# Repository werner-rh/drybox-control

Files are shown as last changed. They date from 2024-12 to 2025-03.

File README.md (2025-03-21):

DryBox dryController
===

## Version 0.50 ESP 01

## Requirements
- Arduino IDE 1.8.2 or higher
- NewliquidCrystal (I2C) https://github.com/fmalpartida/New-LiquidCrystal/tree/master
- ESP8266: PubSubClient by Nick O'Leary
- SEP8266: ArduinoJson by Benoit Blanchon

- 3D printing files and other parts list: https://www.printables.com/de/model/724722-filament-dry-box-heated-ventilated-arduino-control
- Improved version: https://www.printables.com/model/1093573-enhanced-filament-dry-box-heated-ventilated-arduin

## Description
Controller for an active heated and ventilated Filament DryBox. The Dryer contains a PTC Heater and a Fan for fresh dry air.

Original version is for Arduino Nano
Improved Version is for Wemos D1 Mini (ESP8266); additional features:
- sensor data transmission via mqtt
- example files for mqtt --> telegraf --> influxdb --> grafana
- PCB layout in kicad
- ==> pay attention to set your wifi credentials in Secrets.h (for ESP8266)

With one Heater, the box may barely reaches 55 degree. As max i reached 57 degree. I recommend not to go over 52-53 degree. If you need higher temperatures, install a second heater. The MosFet switch will manage this. But you also need a stronger power supply (12V, 8-10A). A simple improvement is insulating the walls inside. I used a car sun protect shield, with reflection and insulating. This improves the performance of the box sigifignant. The warm up is much faster and also eaysier to to reach 55 degrees.

## Recommended drying temperatures
- PLA, PLA+                : 40-45 degree
- ABS, ABS+,  PETG         : 45-50 degree
- PVA,PVB, ASA, TPU, PMMA  : 50-55 degree

## Trouble shooting for ESP8266 version
- Check step by step in the chain  esp --> mqtt --> telegraf --> influxdb --> grafana
- Let DryBox run for all of the following tests.
- esp: Check the serial console: Is wifi working? Do you have a mqtt connection? Have you changed the corresponding parameters in Secrets.h?
- mqtt: Use the commandline or the tool mqtt explorer to observe the mqtt messages from DryBox. There should be a main node labeled like in Secrets.h
- telegraf: telegraf has input and output interfaces. First check the log for any errors in the input interface. Then check if the output interface wrote into the file listed in telegraf.conf. If this is working, you can comment out the file section in telegraf.conf. Now check telegraf´s output interface to influxdb. Do you have set the influxdb token in telegraf.conf?
- influxdb: Have you generated a bucket "DryBox" an configured this in Secrets.h? Have you generated a token connected to the bucket for telegraf and grafana with the necessary permissions? Use the influxdb data explorer to check if any DryBox data is written from telegraf.
- grafana: Have you created a datasource "InfluxDB" with query language "flux"? Is the organization (e.g. "Homelab") the same in the config files for telegraf, influxdb and grafana? Did you use the right token from influxdb? Did you select the configured datasource when importing the grafana.json file?

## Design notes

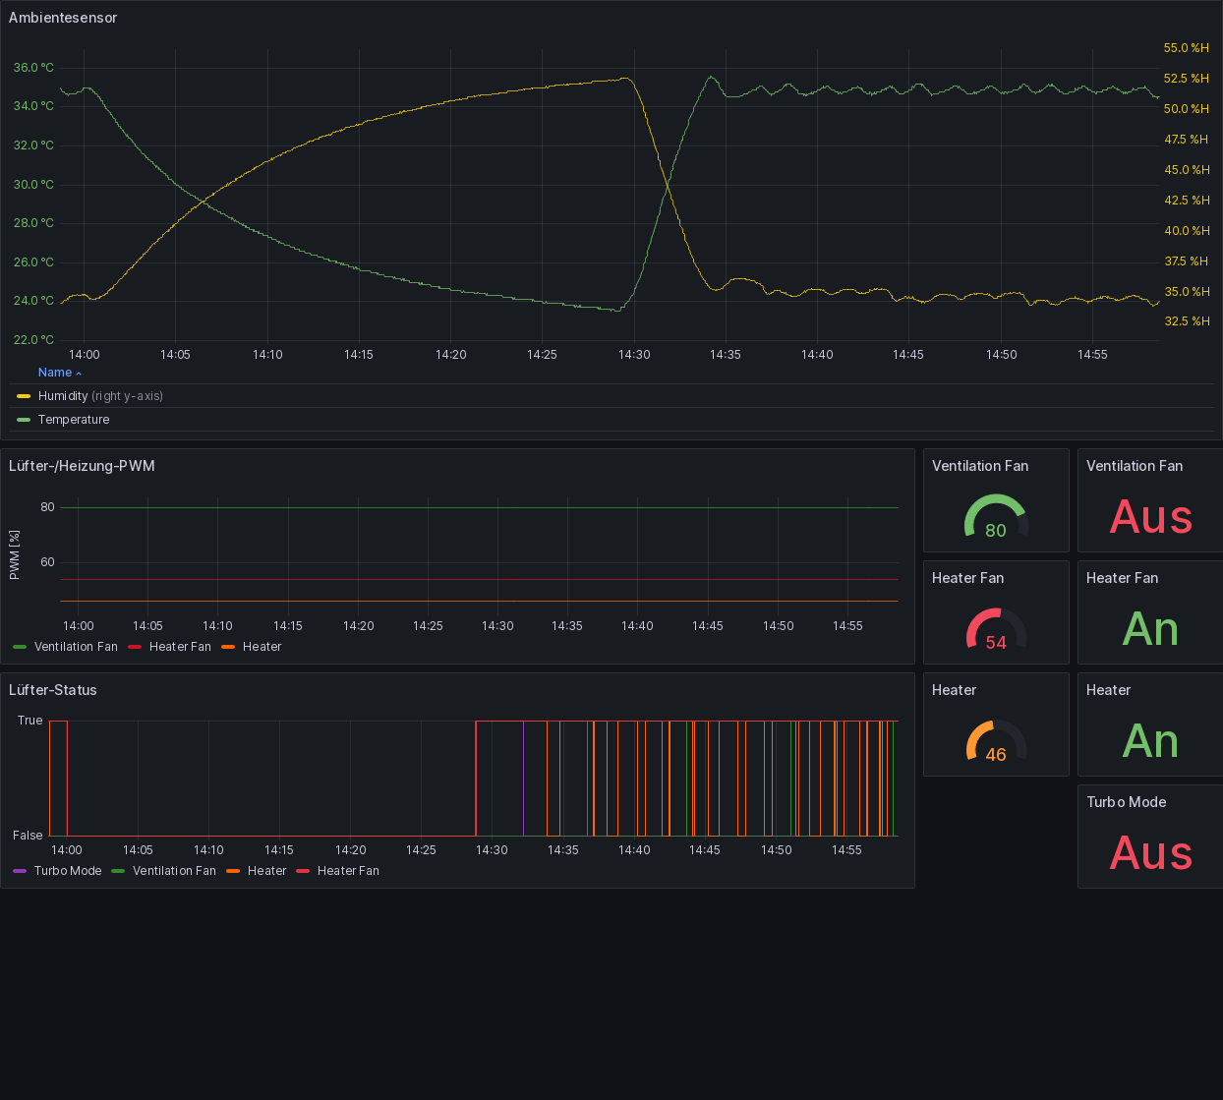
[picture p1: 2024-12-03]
helpers/DryBox-Dashboards-Grafana.png

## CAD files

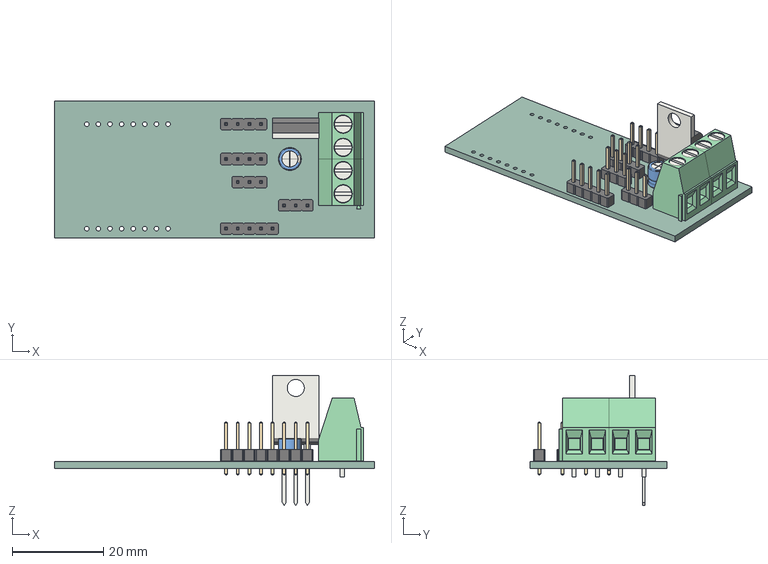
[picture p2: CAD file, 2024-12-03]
DryBoxControlPlatine/DryBoxControlPlatine.step
70.0 x 30.0 x 28.5 mm
DryBoxControlPlatine PCB

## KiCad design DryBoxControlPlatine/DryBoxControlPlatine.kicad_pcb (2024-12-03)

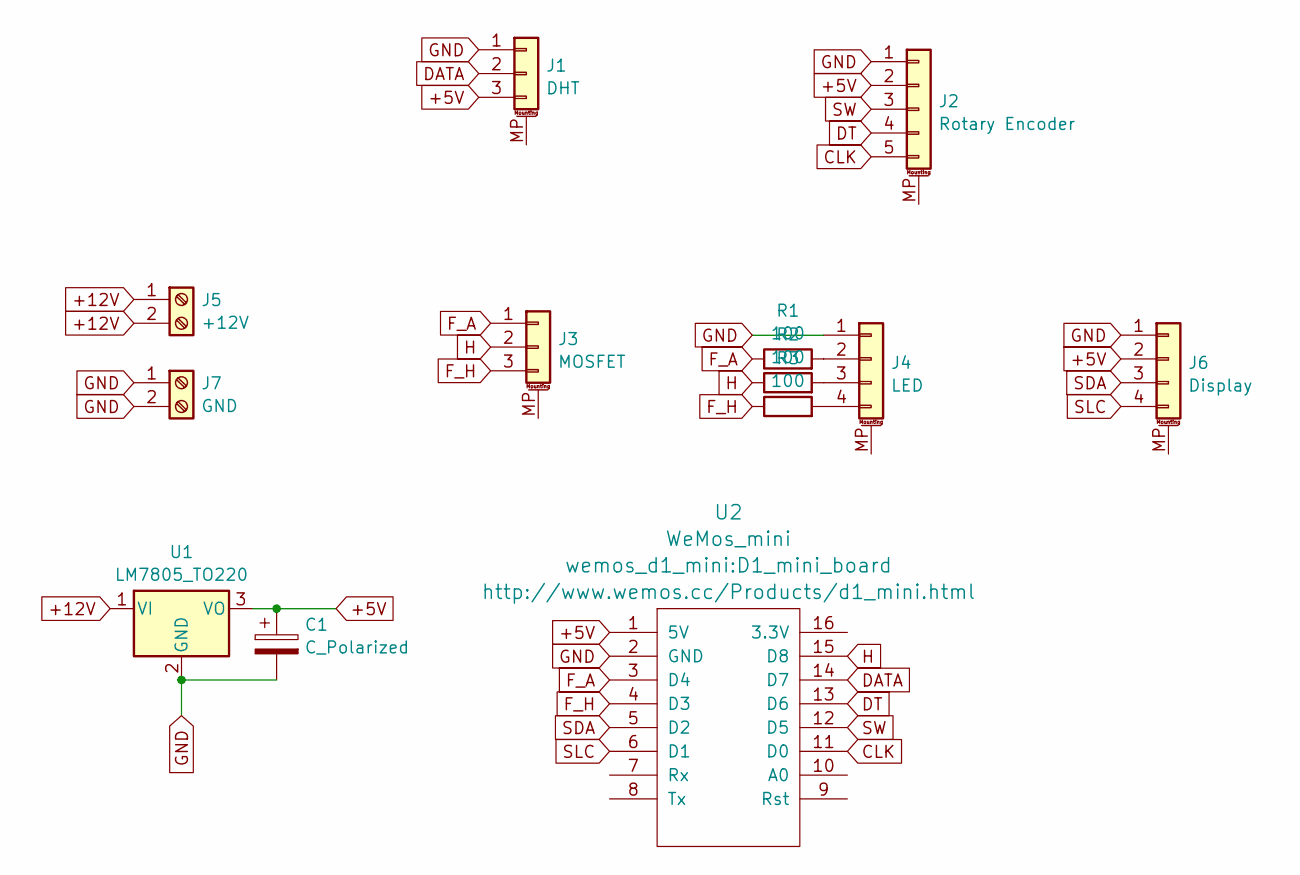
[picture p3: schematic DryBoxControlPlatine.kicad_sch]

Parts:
C1: C_Polarized; CP_Radial_D5.0mm_P2.50mm
J1: DHT; PinHeader_1x03_P2.54mm_Vertical
J2: Rotary Encoder; PinHeader_1x05_P2.54mm_Vertical
J3: MOSFET; PinHeader_1x03_P2.54mm_Vertical
J4: LED; PinHeader_1x04_P2.54mm_Vertical
J5: +12V; TerminalBlock_Phoenix_MKDS-1,5-2-5.08_1x02_P5.08mm_Horizont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
J6: Display; PinHeader_1x04_P2.54mm_Vertical
J7: GND; TerminalBlock_Phoenix_MKDS-1,5-2-5.08_1x02_P5.08mm_Horizont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
R1, R2, R3: 100; R_Axial_DIN0204_L3.6mm_D1.6mm_P2.54mm_Vertical
U1: LM7805_TO220; TO-220-3_Vertical
U2: WeMos_mini; D1_mini_board

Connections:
+5V: C1.1, J1.3, J2.2, J6.2, U1.3 (VO), U2.1 (5V)
+12V: J5.1, J5.2, U1.1 (VI)
CLK: J2.5, U2.11 (D0)
DATA: J1.2, U2.14 (D7)
DT: J2.4, U2.13 (D6)
F_A: J3.1, R1.1, U2.3 (D4)
F_H: J3.3, R3.1, U2.4 (D3)
GND: C1.2, J1.1, J2.1, J4.1, J6.1, J7.1, J7.2, U1.2 (GND), U2.2 (GND)
H: J3.2, R2.1, U2.15 (D8)
unnamed: J4.2, R1.2
unnamed: J4.3, R2.2
unnamed: J4.4, R3.2
SDA: J6.3, U2.5 (D2)
SLC: J6.4, U2.6 (D1)
SW: J2.3, U2.12 (D5)

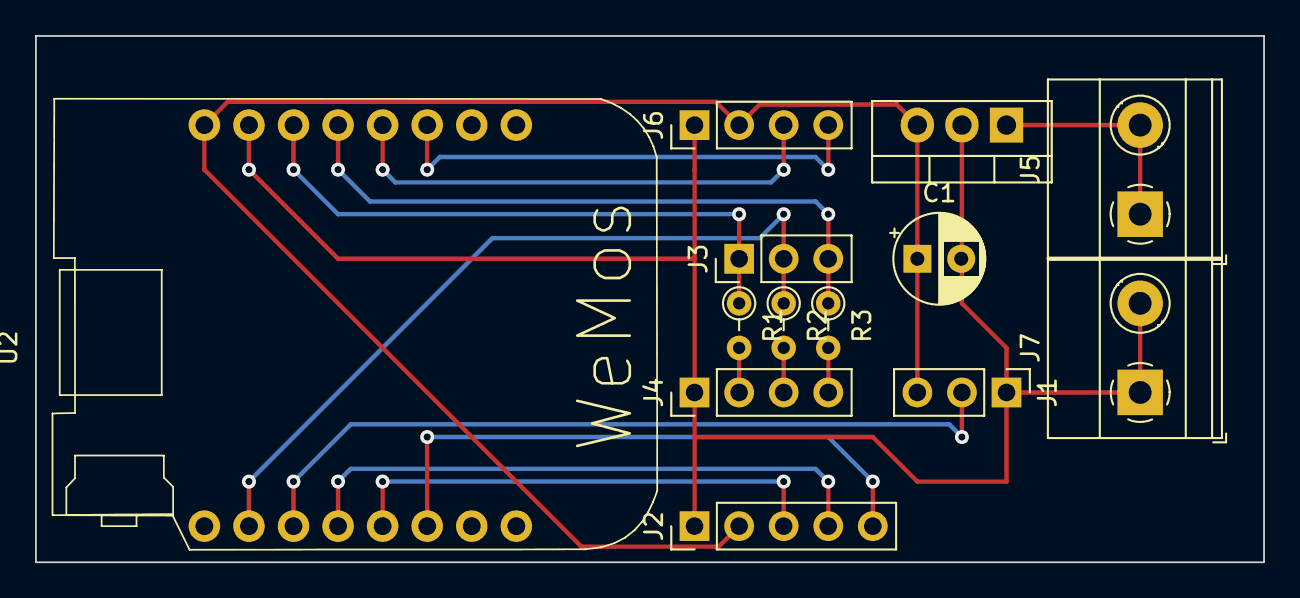
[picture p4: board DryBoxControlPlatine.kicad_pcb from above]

Board: 2 copper layers, 70.0 x 30.0 mm, 13 parts (0 on the bottom side), 15 nets.

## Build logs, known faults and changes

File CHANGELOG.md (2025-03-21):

# Changelog
All notable changes for this project will be documented in this file

## [0.50 ESP 01] - 2025-03-21
### Added
- Trouble shooting guide for ESP in README
### changed
- grafana.json for better import management without UIDs
- Versioning for ESP branch now with separate version tag
 
## [0.50] - 2024-12-02
### Added
- Port to platform ESP8266 (Wemos D1 Mini): software timer interrupt handling; wifi; Secrets.h for wifi and mqtt config
- MQTT for ESP8266: Publish sensor data
- ESP8266: Example configs for telegraf and grafana for transport and visualisation of sensor data
- ESP8266: PCB layout
### changed
- Handling sensor error: Added a retry mechanism for reading sensor data if sensor is temporarily offline.

## [0.49] - 2024-06-18
### Added
- Handling sensor error. If sensor fails during drying cycle, then drying process will be stopped and error message appear on the screen.
  
## [0.48] - 2024-05-08
### changed
- Refactoring Heating data. All values for heating power and heater fan speed are handled in an own class 
### Added
- Turbo mode for faster heating up in the lower ranges
- values for ventialtion time and final ventilation time
- replaced fix define for air exchange intervall with value in HeatingData

## [0.47] - 2024-05-05
### changed
- bugfix in function dryController(). Heater now is shut down after ventilation.
- bugfix in rampUpTable. Range over 50 degrees wasn't regarded and so powered to low.
### Added
- additional range over over 45 and 50 degrees. Now there are 6 ranges.
- display showing state of heater, heaterfan and ventilation during drying.
- refactored initializing power values for each tempeture range.
- adjust current values for low Hysteresis

## [0.46]
### Added
- last final ventilation after dry process is finished

## [0.45]
### Added
- first final version

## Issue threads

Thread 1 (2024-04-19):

avoid temp overshoot

derFliegendeHamburger, 2024-04-19:
as general safety measure or if heater runs during ventilation phase, the temp could rise way above the desired target drying temperature.
cure: add a test and emergency stop for the heater  right after reading the sensor.

werner-rh, 2024-04-19:
The heater only runs until the destination temperature is reached. The it is switched off. The heater also don't run during ventilation. After switch off the heater doesn't cool down immediately. So the temperature may increase a lttle bit over the destination. This is a normal Hysteresis in temperature controll processes.

Anyway, the heater is a PTC element. It can't overheat.

werner-rh, 2024-04-19:
There is no need for an emergency stop within the normal Hysteresis. The temperature is reading as fast as the DHT11 is able to deliver and the values are immediately handled.

Closed 2024-04-19.

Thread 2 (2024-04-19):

timing is wrong by factor 2

derFliegendeHamburger, 2024-04-19:
in my setup I have to half the timing counters from 100 down to 50 and from 6000 down to 3000 respectively to get proper timing

werner-rh, 2024-05-06:
there might be something wrong on your side. The timing is controlled by interrupt in chain of the milli second timer. My timing fits like a swiss clock. Are you using something different? Usb serial or some other thing?

derFliegendeHamburger, 2024-05-11:
different hardware, yes. For arduino software relevant differences are
i2c sensor SHT41, 4-pin pwm fans require 4kHz pwm signal, 20x4 display, usb debug output.

werner-rh, 2024-05-12:
The usb debug output might crash your timing. Have you tried it without usb serial output?

derFliegendeHamburger, 2024-05-17:
yes, no difference.
I can see my other problem related to timing - the display gets garbled. From past projects I know this happens when the display (driver and or firmware and or hardware) suffers from too frequent requests.
Not sure if the 20x04 display is particularly slow but I like the extra space for output.
It will take some more time to diagnose this further and possibly adopt code accordingly.

werner-rh, 2024-05-18:
I never tried a 20x4 until now. The two lines more might be the problem, because they are forcing a lot more traffic on the I2C. Even with the 16x2 display, only particluar ranges are updated, because this also needs a lot of time. Maybe you can use a parallel interface for the display. That would be much faster. The DryBox it self doesn't need much I/Os.

derFliegendeHamburger, 2024-05-26:
- reduced i2c bus speed to 100kHz,
- replaced 4wire ribbon cable for  i2c wiring to i2c sensor sht41 with shorter CAT5 shielded cable
working, solved

werner-rh, 2024-06-01:
Sounds good! Great!

Closed 2024-05-26.

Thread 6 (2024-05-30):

Question wrt to ventilation cycle

derFliegendeHamburger, 2024-05-30:
in the process of drying, the ventilation is activated every 4 minutes with 20 seconds runtime.
Are these specifics accidental or do you have any 'theory' or testing scheme behind this?

Reason for me asking is that my drybox is built to hold 4Kg spools, so it is quite larger and holds more air and more mass than the typical dryer.

werner-rh, 2024-06-01:
The interval of 4 minutes and 20 seconds are evaluated with the 10L Box. In combination i had a good ventilation for this box and not to much temperature drop. For a 4kg spool, your box must be quite bigger. So you have to find out, which are the best parameter. Take a look at version 0.48. I have refactored the code a bit and you now have all adjustable parameter at one place in file HeatinData.cpp. This might be easier to try out the parameters you need.

werner-rh, 2024-07-04:
can be closed

Closed 2024-07-04.

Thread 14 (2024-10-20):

Misspelling of PWM

jofland, 2024-10-20:
Misspelling in HeatingData.h

```
uint8_t ventilationFanPWN;
//PWN
```

should be

```
uint8_t ventilationFanPWM;
//PWM
```

werner-rh, 2024-12-03:
Fixed in v0.49.1

Closed 2024-12-03.

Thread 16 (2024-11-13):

Encoder Button not configured

bmchughs, 2024-11-13:
I had issue with the Arduino sketch, specifically the encoder 'button' was not working.  Looking at the sketch I included the code below on line 157 and it resolved the issue.

` pinMode(EncSwitch, INPUT_PULLUP);`

I don't see that the 'EncSwitch' was configured to be an 'input' anywhere in the sketch.  Once I included this bit of code, it worked perfectly fine.

werner-rh, 2024-12-01:
Yes you are right. I found it now. But i don't know why, my Encoder works fine even without the input config ;) - i will fix it.

werner-rh, 2024-12-03:
Fixed in v0.49.1

Closed 2024-12-03.

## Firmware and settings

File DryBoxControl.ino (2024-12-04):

/***
   Project: DryBox Control
   File   : DryBoxControl.ino
   Author : Werner Riemann
   Created: 18.10.2023
   Board: Arduino Nano

   Description: Controller for an active (heated) Filament DryBox.
                The Dryer contains a PTC Heater and a Fan for fresh dry air.

   Recommended drying temperatures:
      PLA, PLA+                : 40-45 degree
      ABS, ABS+,  PETG         : 45-50 degree
      PVA,PVB, ASA, TPU, PMMA  : 50-55 degree

     Note: with one Heater, the box may barely reaches 55 degree. As max i reached 57 degree.
           I recommend not to go over 52-53 degree. If you need higher temperatures,
           install a second heater. The MosFet switch will manage this. But you
           also need a stronger power supply (12V, 8-10A).

   Pins:

   Arduino
   A4,A5  - I2C Display control (A4 - SDA, A5 - SCL)
   Wemos D1 Mini
   5=D1, 4=D2  - I2C Display control (D2 - SDA, D1 - SCL)



   D2     - not used
   D1     - not used
   D3     - not used
   D4     - not used

   Arduino
   D5     - Rotary Encoder Switch
   D6     - Rotary Encoder DT_pin                 Note: some encoder are different and you may have to change DT and CLK Pin.
   D7     - Rotary Encoder CLK_pin                      Clockwise spin should increase all values.
   D8     - Digital in DHT11 sensor
   D9     - Analog out PWM Fan Air exchange
   D10    - Analog out PWM Fan Heating
   D11    - Analog out PWM Heating
   D12    -

   Wemos D1 Mini
   14=D5     - Rotary Encoder Switch
   12=D6     - Rotary Encoder DT_pin                 Note: some encoder are different and you may have to change DT and CLK Pin.
   16=D0     - Rotary Encoder CLK_pin                      Clockwise spin should increase all values.
   13=D7     - Digital in DHT11 sensor
   0=D3     - Analog out PWM Fan Air exchange
   2=D4     - Analog out PWM Fan Heating
   15=D8    - Analog out PWM Heating

   D13    - Digital out LEDPIN 13 (interne LED)


   --- Menu and functions ---
   Main select: Temperature, Time, Start, Save, Version, Test functions (press Rotary to choose)
   Temperature: change value by rotate, press to Rotary to exit
   Time       : choose hour, minutes or Ret to exit. Press Rotary to enter value to change. Press Rotary again to exit value change.
   Start      : press Rotary to start drying. Press Rotary during drying to pause or exit drying
   Save       : press Rotary to save current setting for temperature and time to eeprom
   Version    : shows the current version, press Rotary again to return to main
   Test       : provides 3 functions for Heater, Heater Fan, Air Fan for Fresh air supply and exit Test.
                On exit Test menu, all values are set to zero and stops all modules.

                This is useful to check all modules separately after assembling modules. Keep in mind to don't power
                up the heater without the fan for a longer time.
*/

#include <SPI.h>
#include <Wire.h>
#include <EEPROM.h>
#include <Arduino.h>
#include <DHT.h>
#include "DryBoxControl.h"
#include "WRKeyStateDef.h"
#include "DryBoxDisplay.h"
#include "HeatingData.h"

#ifdef ESP8266
  #include <Ticker.h>
  #include <ESP8266WiFi.h>
  #include <PubSubClient.h>
  #include <ArduinoJson.h>
  #include "Secrets.h"
#endif

// defines for DHT11 Temp and Humitidy Sensor
#ifdef ARDUINO_AVR_NANO
  #define DHTPIN 8        // Digital pin connected to the DHT sensor
  int EncSwitch = 5;
  int DT_pin = 6;   //swap lines to change direction on the encoder
  int CLK_pin = 7;  //swap lines to change direction on the encoder
#elif ESP8266
  #define DHTPIN 13        // Digital pin connected to the DHT sensor
  int EncSwitch = 14;
  int DT_pin = 16;   //swap lines to change direction on the encoder
  int CLK_pin = 12;   //swap lines to change direction on the encoder
  Ticker timer;
  bool mqttConnected = false;
#else
  #error "Unsupported platform"
#endif

//#define DHTTYPE DHT11   // chose the DHT type you are using
#define DHTTYPE DHT22

volatile uint8_t B100HzToggle = 0;  // 100 Hertz Signal
uint8_t ui10MilliSekCount = 0;

int encoder_value = 500;
int last_encoder_value  = 500;
int DT_pinstate;
int last_DT_pinstate;

int AirFanSpeed = 100;    // Extract Fan Speed in Percent
int HeatFanSpeed = 50;    // HeatFan Speed in Percent
int HeatingPower = 25;    // Heating Power in Percent

int testAirFanSpeed = 0;    // Extract Fan Speed in Percent for testing mode
int testHeatFanSpeed = 0;   // HeatFan Speed in Percent for testing mode
int testHeatingPower = 0;   // Heating Power in Percent for testing mode

// default values at startup, if nothing is stored in the eeprom
int DryTemperature = 35;    // Destination Dry Temperature in degree celsius
int DryTime_Hours = 1;
int DryTime_Minutes = 30;
int curDryTime_Hours = 1;
int curDryTime_Minutes = 30;

//-- adjustable seetings for drying process, stored in HeatingData class
HeatingData heatingData;    // see HeatingData class


//-- State var for rotary encoder weitch  ----
uint8_t encoderBUTTON_State = 0;

//-- Remember State on for Heater, Heater Fan and Ventilation
boolean StateHeaterOn = false;
boolean StateHeaterFanOn = false;
boolean StateVentilationOn = false;
boolean turboMode = false;

DryBoxDisplay display;
DHT dht(DHTPIN, DHTTYPE);

#ifdef ESP8266
  WiFiClient espClient;
  PubSubClient mqtt_client(espClient);
  
  void connectToWiFi() {
    WiFi.begin(ssid, password);
    Serial.print("Connecting to WiFi");
    unsigned long startAttemptTime = millis();
    const unsigned long timeout = 10000;
  
    while (WiFi.status() != WL_CONNECTED && millis() - startAttemptTime < timeout) {
      delay(500);
      Serial.print(".");
    }
    if (WiFi.status() == WL_CONNECTED) {
      Serial.println("\nConnected to the WiFi network");
    } else {
      Serial.println("\nFailed to connect to WiFi. Continuing without WiFi.");
    }
  }
  
  
  void connectToMQTTBroker() {
    unsigned long startAttemptTime = millis();
    const unsigned long timeout = 5000;
    if (!WiFi.isConnected()) {
      return;
    }

    while (!mqtt_client.connected() && millis() - startAttemptTime < timeout) {
      String client_id = String(mqtt_topic) + String("-")  + String(WiFi.macAddress());
      Serial.printf("Connecting to MQTT Broker as %s.....\n", client_id.c_str());
      if (mqtt_client.connect(client_id.c_str(), mqtt_username, mqtt_password, (String(mqtt_topic) + "/status").c_str(), 0, true, "offline")) {
        Serial.println("Connected to MQTT broker");
        mqttConnected = true;
        mqtt_client.setBufferSize(1024);
        mqtt_client.subscribe(mqtt_topic);
        mqtt_client.publish((String(mqtt_topic) + "/status").c_str(), "online", true);
        return;
      } else {
        Serial.print("Failed to connect to MQTT broker, rc=");
        Serial.print(mqtt_client.state());
        Serial.println(" try again...");
      }
      delay(1000);
    }
    mqttConnected = false;
  }
#endif



/***
   Saves the current settings for temperature, drying hours and minutes
*/
void SaveSettings() {
  EEPROM.write(0, (uint8_t) 17);
  EEPROM.write(1, (uint8_t) DryTemperature);
  EEPROM.write(2, (uint8_t) DryTime_Hours);
  EEPROM.write(3, (uint8_t) DryTime_Minutes);
}


/***
   Reads the last saved settings for temperature, drying hours and minutes
*/
void ReadSettings() {
  uint8_t isInit = EEPROM.read(0);

  if (isInit == 17) {
    DryTemperature = EEPROM.read(1);
    DryTime_Hours = EEPROM.read(2);
    DryTime_Minutes = EEPROM.read(3);
  }
}


// Interrupt is called once a millisecond,
#ifdef ARDUINO_AVR_NANO
  SIGNAL(TIMER0_COMPA_vect)
#elif ESP8266
  void myTimerFunction()
#endif
{
  unsigned long currentMillis = millis();
  ui10MilliSekCount ++;

  if (ui10MilliSekCount >= 10 ) {
    ui10MilliSekCount = 0;
    B100HzToggle ^= 1;
  }

  ReadEncoder();
}

void setup() {
  Serial.begin(115200);
  Serial.println("Start");
  // setup Rotary encoder
  pinMode (EncSwitch, INPUT);
  pinMode (DT_pin, INPUT);
  pinMode (CLK_pin, INPUT);
  digitalWrite(EncSwitch, HIGH);  // enable intern pull up resistor
  digitalWrite(DT_pin, HIGH);
  digitalWrite(CLK_pin, HIGH);

  // setup Heating and air
  pinMode(FANAIR_PIN, OUTPUT);
  analogWrite(FANAIR_PIN, 0);            // PWM Extrcat Fan off
  pinMode(FANHEATING_PIN, OUTPUT);
  analogWrite(FANHEATING_PIN, 0);        // PWM Heating Fan  off
  pinMode(HEATING_PIN, OUTPUT);
  analogWrite(HEATING_PIN, 0);           // PWM Heating off

  ReadSettings();

  // Reads the initial state of DT
  last_DT_pinstate = digitalRead(DT_pin);

  display.Setup();
  display.SetVersion(APP_VERSION);
  display.ScreenOut(SCR_WELCOME);
  dht.begin();                      // start DHT

  // Timer setup --------------------------
#ifdef defined(ARDUINO_AVR_NANO)
  // Timer0 is already used for millis() - we'll just interrupt somewhere
  // in the middle and call the "Compare A" function below
  OCR0A = 0xAF;
  TIMSK0 |= _BV(OCIE0A);
#elif ESP8266
  timer.attach_ms(1, myTimerFunction);

  connectToWiFi();
  mqtt_client.setServer(mqtt_broker, mqtt_port);
  connectToMQTTBroker();
#endif

}

void ReadEncoder() {
  DT_pinstate = digitalRead(DT_pin);
  if (DT_pinstate != last_DT_pinstate) { //did DT changed state?
    if (digitalRead(CLK_pin) == DT_pinstate) { // if DT changed state, check CLK
      encoder_value--; // rotation is counter-clockwise, decrement the value
    } else {
      encoder_value++; // rotation is clockwise, increment the value
    }
    last_DT_pinstate = DT_pinstate; //save the last state of DT
  }
}


/***
   EncoderValueChange - increments or decrements the value of given var depending
   from the direction the rotary encoder is moved. The Value of var is kept in range
   of rangeMin and rangeMax.

   param int * valToModify : pointer of var to modify
   param int rangeMin: minimum value
   param int rangeMax: maximum value
*/
void EncoderValueChange(int * valToModify, int rangeMin, int rangeMax) {
  int aktValue = * valToModify;

  if (last_encoder_value != encoder_value)
  {

    if (encoder_value > last_encoder_value + 1)
    {
      last_encoder_value = encoder_value;
      if (aktValue < rangeMax)
        aktValue ++;
    }

    if (encoder_value + 1  < last_encoder_value )
    {
      last_encoder_value = encoder_value;
      if (aktValue > rangeMin)
        aktValue --;
    }
  }

  * valToModify = aktValue;
}


boolean IsPWMStateOn(int pwmValue) {
  if (pwmValue > 0)
    return true;
  else
    return false;
}

void SetPWMRate(uint8_t pin, int ratePercent)
{
  int PWMVal = 255 * ratePercent / 100;
  analogWrite(pin, PWMVal);

  // check which Pin (heater, heater fan or ventilation) and store the state on or off
  switch (pin) {
    case FANAIR_PIN: StateVentilationOn = IsPWMStateOn(PWMVal);
      break;
    case FANHEATING_PIN: StateHeaterFanOn = IsPWMStateOn(PWMVal);
      break;
    case HEATING_PIN: StateHeaterOn = IsPWMStateOn(PWMVal);
      break;
  }
}


// Main loop -----------------------------------------------------------
void loop() {
  static uint8_t AppState = 0;
  static uint8_t StateTrigger = 0;
  uint8_t aktStateTrigger;
  static int aktModeNo = 1;
  static int aktTestModeNo = 1;
  static int aktTimeEdMode = 1;  // 1= edit hour, 2= minutes, 3= exit edit
  static int aktBreakModNo = 1;

  static uint8_t ui100HzSecCounter = 0; // counter for a second
  static uint8_t ui100HzSensorTimer = 200; // read DHT11 sensor every 2 seconds
  static int runMinuteTimer = 6000;
  static int airExChgEndCounter = 2000;
  static float humidity = 0.0;
  static float temperature = 0.0;

  int oldHeatFanSpeed = 0;
  int oldAirFanSpeed = 0;
  int oldHeatingPower = 0;
  int oldModeNo = 0;
  int oldTestModeNo = 0;
  int oldTimeEdMode = 0;
  int oldDryTemperature = 0;
  int oldTimeVal = 0;
  int oldBreakModNo = 1;
  uint8_t oldAppState = 0;
  int nan_count = 0;

  char szBuf[8];

  aktStateTrigger = B100HzToggle;

#ifdef ESP8266
  StaticJsonDocument<200> jsonStatus;
  StaticJsonDocument<1024> jsonData;
  char jsonBuffer[10124];
#endif

  // Processing State-Machine. ----------------------------------------------------------
  // The state machine is triggered on every Change of flank of the timer toogle.
  // This happens 100 times in a second.

  if (aktStateTrigger != StateTrigger) {
    StateTrigger = aktStateTrigger;

    CheckKeyState(&encoderBUTTON_State, EncSwitch);

#ifdef ESP8266
    if (mqttConnected) {
      mqtt_client.loop();
      if (!mqtt_client.connected()) {
        connectToMQTTBroker();
      }
    }
    jsonStatus["status"] = "online";
#endif
    
    // The DHT11 is a little slow,. So we shouldn't
    // receive values too quickly
    if (ui100HzSensorTimer > 0) {
      ui100HzSensorTimer--;
    } else {
      ui100HzSensorTimer = 200;
      humidity = dht.readHumidity();
      temperature = dht.readTemperature();
      // Check for NaN values
      if (isnan(humidity) || isnan(temperature)) {
        nan_count++;
        if (nan_count >= 3) {
          // Stop the drying process if NaN values are detected
          dryController(DST_TEARDOWN, temperature);
          display.ScreenOut(SCR_ERROR);
          display.PrintError("DHT Sensor Error"); // Display error message
          AppState = AST_IDLE; // Transition to a safe state
          dht.begin();
          nan_count = 0;
        }
      } else {
        nan_count = 0;
      }
      if ((AppState == AST_MODE_SELECT || AppState == AST_RUNDRYING || AppState == AST_TESTMODE) && nan_count == 0) {
        display.PrintTHValue(temperature, humidity);
#ifdef ESP8266
        JsonObject measurement = jsonData.createNestedObject("measurement");
        measurement["temperature"] = String(temperature, 1) + " °C";
        measurement["humidity"] = String(humidity, 0) + " %";

        JsonObject rawMeasurement = jsonData.createNestedObject("raw");
        rawMeasurement["temperature"] = temperature;
        rawMeasurement["humidity"] = humidity;

        JsonObject heater = jsonData.createNestedObject("heater");
        heater["StateHeaterOn"] = StateHeaterOn;
        heater["StateHeaterFanOn"] = StateHeaterFanOn;
        heater["StateVentilationOn"] = StateVentilationOn;
        heater["turboMode"] = turboMode;
        heater["DryTemperature"] = DryTemperature;
        heater["DryTime_Hours"] = DryTime_Hours;
        heater["DryTime_Minutes"] = DryTime_Minutes;
        heater["curDryTime_Hours"] = curDryTime_Hours;
        heater["curDryTime_Minutes"] = curDryTime_Minutes;
        heater["ventilationHeaterPWM"] = heatingData.ventilationHeaterPWM;
        heater["ventilationHeaterFanPWM"] = heatingData.ventilationHeaterFanPWM;
        heater["ventilationFanPWM"] = heatingData.ventilationFanPWM;

        serializeJson(jsonData, jsonBuffer);
        mqtt_client.publish((String(mqtt_topic) + "/data").c_str(), jsonBuffer);
#endif
      }
    }
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

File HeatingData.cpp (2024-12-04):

/***
 * Project: DryBox Control
 * File   : HeatingData.h
 * Author : Werner Riemann 
 * Created: 08.05.2024
 * Board: Arduino Nano
 * 
 * Description: Implementation of Class HeatingData
 *              Class for handling the values for heating power and heater fan speed
 *              depending on the different temperature ranges
 * 
 */

#include "HeatingData.h"

HeatingData::HeatingData()
{

}


/***
* Setup all values needed to controll heater power, heater fan speed and ventilation speed.
* 
  we are using the same variables for each temperature range. But depending which range, 
  they are populated with the appropriate values.

  The method is initializing following member variables. All values, except compareOffset, compareOffsetTurboMode and airExtractionTime, 
  are percentage values for the PWM to power heater or fan. compareOffset and compareOffsetTurboMode are float temperature
  value in degree celsius.

  uint8_t rampUpHeatPWM[3]            - ramp values will be generated by software on calling SetupHeatingValues
  uint8_t defaultHeaterPWM            - final value to power the heater during drying
  uint8_t defaultHeaterFanPWM         - final value to power the heater fan during drying
  uint8_t nearDestHeaterPWM           - power value for heater near before destination temperature
  uint8_t lowHeaterFanPWM             - heater fan power value, when destinatiion temp is reached and heater is switched off
  uint8_t turboHeaterPWM              - power value for heater turbo mode for quicker heat up
  uint8_t turboHeaterFanPWM           - power value for heater fan turbo mode for quicker heat up
  float compareOffset                 - value below destination temperature, when heater is switched to a lower power
  float compareOffsetTurboMode        - value below destination temperature, when heater is switched to default power
  uint8_t ventilationHeaterPWM        - power value for heater during ventilation
  uint8_t ventilationHeaterFanPWM     - power value for heater fan during ventilation
  uint8_t ventilationFanPWM           - power value for ventilation fan during ventilation
  uint8_t airExtractionTime;          - air extraction time in seconds, done in intervalls during drying process
  uint8_t finalAirExtractionTime      - final air extraction time in seconds after finishing drying process
  uint8_t airExchangeIntervallMinutes - air exchange intervall in minutes
*/
void HeatingData::SetupHeatingValues(int dryDestTemp)
{

  ventilationFanPWM = 80;       // for the ventilation fan we only need one value for all
  airExtractionTime = 20;
  finalAirExtractionTime = 30;
  airExchangeIntervallMinutes = 5;    // don't set this value less then 4
  
  /*-- range up to 32 degree celsius -- */
  if(dryDestTemp <= 32) {
    defaultHeaterPWM = 72;
    defaultHeaterFanPWM = 72;
    nearDestHeaterPWM = 44;
    lowHeaterFanPWM = 32; 
    turboHeaterPWM = 92;
    turboHeaterFanPWM = 90;
    compareOffset = 0.5;
    compareOffsetTurboMode = 4.0;
    ventilationHeaterPWM = 40;
    ventilationHeaterFanPWM = 52;
  }

  /*-- range over 32 up to 35 degree celsius -- */
  if(dryDestTemp > 32 && dryDestTemp <= 35) {
    defaultHeaterPWM = 80;
    defaultHeaterFanPWM = 76;
    nearDestHeaterPWM = 58;
    lowHeaterFanPWM = 34; 
    turboHeaterPWM = 94;
    turboHeaterFanPWM = 90;
    compareOffset = 0.5;
    compareOffsetTurboMode = 4.0;
    ventilationHeaterPWM = 46; //
    ventilationHeaterFanPWM = 54;
  }

  /*-- range over 35 up to 40 degree celsius -- */
  if(dryDestTemp > 35 && dryDestTemp <= 40) {
    defaultHeaterPWM = 88;
    defaultHeaterFanPWM = 78;
    nearDestHeaterPWM = 62;
    lowHeaterFanPWM = 40; 
    turboHeaterPWM = 98;
    turboHeaterFanPWM = 90;
    compareOffset = 0.3;
    compareOffsetTurboMode = 3.0;
    ventilationHeaterPWM = 54;
    ventilationHeaterFanPWM = 34;
  }

  /*-- range over 40 up to 45 degree celsius -- */
  if(dryDestTemp > 40 && dryDestTemp <= 45) {
    defaultHeaterPWM = 88;
    defaultHeaterFanPWM = 82;
    nearDestHeaterPWM = 66;
    lowHeaterFanPWM = 44; 
    turboHeaterPWM = 98;
    turboHeaterFanPWM = 90;
    compareOffset = 0.2;
    compareOffsetTurboMode = 2.0;
    ventilationHeaterPWM = 60; // 56
    ventilationHeaterFanPWM = 40;
  }

  /*-- range over 45 up to 50 degree celsius -- */
  if(dryDestTemp > 45 && dryDestTemp <= 50) {
    defaultHeaterPWM = 96;
    defaultHeaterFanPWM = 86;
    nearDestHeaterPWM = 72;
    lowHeaterFanPWM = 50; 
    turboHeaterPWM = 98;
    turboHeaterFanPWM = 90;
    compareOffset = 0.2;
    compareOffsetTurboMode = 2.0;
    ventilationHeaterPWM = 70;
    ventilationHeaterFanPWM = 40;
  }

  /*-- range over 50 degree celsius -- */
  if(dryDestTemp > 50 ) {
    defaultHeaterPWM = 99;    // 98
    defaultHeaterFanPWM = 89; // 88
    nearDestHeaterPWM = 75;
    lowHeaterFanPWM = 60; 
    turboHeaterPWM = 99;
    turboHeaterFanPWM = 90;
    compareOffset = 0.2;
    compareOffsetTurboMode = 2.0;
    ventilationHeaterPWM = 78;    // 75
    ventilationHeaterFanPWM = 50;
  }

  // setup the ramp
  rampUpHeatPWM[0] = (defaultHeaterPWM /4);
  rampUpHeatPWM[1] = (defaultHeaterPWM /4) * 2;
  rampUpHeatPWM[2] = (defaultHeaterPWM /4) * 3;
}

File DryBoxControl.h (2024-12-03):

/***
 * Project: DryBoxControl
 * File   : DryBoxControl.h
 * Author : Werner Riemann 
 * Created: 18.10.2023
 * Board: Arduino Nano
 * 
 * Description: Controlling Filament DryBox
 * 
 * Pins:
 * A4,A5  - I2C Display control (A4 - SDA, A5 - SCL)
 * 
 * 
 * 
 */

// ensure this library description is only included once
#ifndef DryBoxControl_h
#define DryBoxControl_h

#include <Arduino.h>

#define APP_VERSION "0.50"

// Defines Pins
#ifdef ARDUINO_AVR_NANO
 #define FANAIR_PIN 9
 #define FANHEATING_PIN 10
 #define HEATING_PIN 11
#elif ESP8266
  #define FANAIR_PIN 0
  #define FANHEATING_PIN 2
  #define HEATING_PIN 15
#endif


// Defines Mode selection -------------------------------------------
#define SELMOD_DRYTEMP      1
#define SELMOD_DRYTIME      2
#define SELMOD_DRYSTART     3
#define SELMOD_SAVE         4
#define SELMOD_VERSION      5
#define SELMOD_TESTING      6

// Defines Statemachine ----------------------------------------------
#define AST_IDLE            0

#define AST_PREPARE_SELECT  10
#define AST_MODE_SELECT     11

#define AST_SET_DRYTEMP     20

#define AST_SET_DRYTIME     30
#define AST_ED_DRYHOUR      31
#define AST_ED_DRYMINUTE    32
#define AST_ED_DRYRET       33

#define AST_RUNDRYING       40
#define AST_RUNPAUSE        41
#define AST_ENDVENTILATION  42

#define AST_TESTMODE        80
#define AST_FAN_CONTROL     81
#define AST_HEAT_CONTROL    82
#define AST_AIR_CONTROL     83

// States for DryController -----
#define DST_STARTUP          1
#define DST_TEARDOWN         2
#define DST_RAMPUP_HEATER    10
#define DST_WAIT_DEST_TEMP   20
#define DST_TEMP_REACHED     30
#define DST_AIR_EXCHANGE     31
#define DST_BREAK            40
#define DST_CONTINUE         41


// Prototypen in CameraSlider.ino ------------------------------------

void SaveSettings();
void ReadSettings();
void ReadEncoder();
void EncoderValueChange(int * valToModify, int rangeMin, int rangeMax);
boolean IsPWMStateOn(int pwmValue);
void SetPWMRate(uint8_t pin, int ratePercent);
void setHeatupRamp(uint8_t rampHeatValues[], uint8_t rampHeatFanValues[], int dryDestTemp,
                   float *compareOffset, uint8_t *nearDestHeaterValue, uint8_t *ventilationHeaterValue);
void dryController(uint8_t doState, float aktTemperature);

#endif

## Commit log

2024-05-08 Add files via upload
    adjust comments and a further fix in dryController
    [DryBoxControl.ino]
2024-05-09 Add files via upload
    refactored heating data and implemented turbo mode
2024-06-10 Update DryBoxControl.ino
    handle sensor error
    [DryBoxControl.ino]
2024-06-19 Update README.md
    adjust version in readme.md to sensor error handling
2024-06-25 Update DryBoxControl.ino
    Fan rpm readout
2024-06-25 Update DryBoxControl.ino
    bug fix in Read fan tachometer
    [DryBoxControl.ino]
2024-06-29 Update DryBoxControl.ino
    minor bug fixes
    [DryBoxControl.ino]
2024-08-04 Add files via upload
    roll back to 0.48 because the fan tacho changes and extension causes compiler error due to uncomplete code
    [DryBoxControl.h, DryBoxControl.ino]
2024-10-20 Ported to Wemos D1 mini (ESP8266); changed to software timer interrupt; added wifi and mqtt; corrected misspelling of pwm
    [DryBoxControl.h, DryBoxControl.ino, HeatingData.cpp]
2024-12-01 PCB (Kicad) for Wemos D1 Mini added
    [DryBoxControlPlatine.kicad_pcb, DryBoxControlPlatine.kicad_sch, DryBoxControlPlatine.step]
2024-12-04 Corrected misspelling of PWM
    [HeatingData.cpp]
2024-12-04 Fixed wrong ESP8266-exclusion of paragraph display error; merged from 0.49.1 issue "Encoder Button not configured" https://github.com/werner-rh/drybox-control/issues/16
    [DryBoxControl.ino]
